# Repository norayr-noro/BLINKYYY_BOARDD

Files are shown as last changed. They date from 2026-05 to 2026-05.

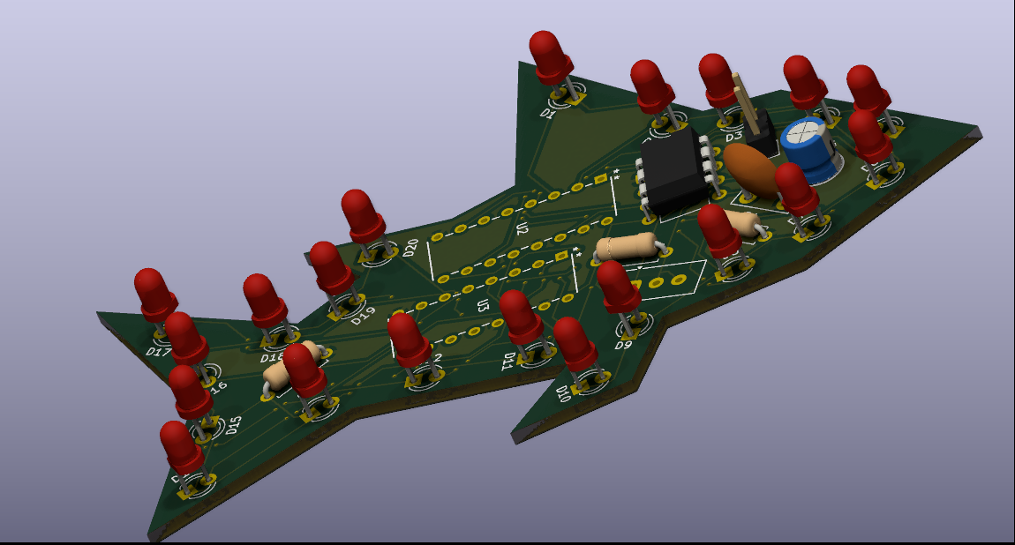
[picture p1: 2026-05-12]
BLINKYY_photos/PCB(3d).png

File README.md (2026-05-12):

# BLINKYYY_BOARDD
This project is based on the stasis guide on the blinky board, where I mostly followed the guide and changed the final look of the PCB to be a FISH (a FIH if you may):

The circuit is based on the original LED chaser design using a 555 timer IC and a CD4017 decade counter. The LEDs light up sequentially, creating a moving animation around the fish-shaped board. While the electronics stay close to the original tutorial, most of the work went into redesigning the PCB layout and making the board look unique.

# Process

The project, first of all, went through the schematic stage as all projects do. It wasn't anything too interesting. For this project ill be using KiCad.  The guide used a 555 chaser and a 4017 IC, which sounds like random letters and words, but kinda makes sense if you think about it. For example, the 555 timer in this build is kinda the "brain" of the whole build, and as far as I understand, the name comes from the 3x 5K ohm internal resistance, while for the IC unit it would help me connect 10 LED's to the board with ease because it has so many pins (think of it as a "spreader" here). Other than those 2 parts, the other parts in the kit are really simple, like an LED, resistors, a polarized (+ and - differentiate in this one, so be careful when wiring!), and a normal capacitor (don't forget the potentiometer too!!).

After understanding what everything dose the next step was to wire all of them, which wasn't difficult at all, except for the wiring for the 555 timer. For context, the timer has 3 modes:
- Monostable (for time delays) mode, which is usually used as a stopwatch
- Astable Mode, which shifts between high and low
- Bistable Mode, which is like a toggle mode (eg a LED turning on and off with different buttons)
For my build, I followed the Astable mode, which has a bit of a weird wiring, but it wasn't too hard.
Also, usually when routing, I learnt it's better to label wires (by pressing A) so it's easier to understand than to wire everything in one fell swoop.
After all of that, the schematic looks a bit like this:

schematic_photo

# The PCB 

Finally, were are onto the PCB designing. Before this, of course you first had to add footprints, obviously. Don't know what they are thinking of symbols and footprints like this, imagine a symbol, something used to understand how a part has to be routed, it's for our case, the symbols are the 555 timer, the IC... everything on the schematic that counts as a part is, and as for footprints Its how the part would look like on the real pcb itself. So I mostly did the same footprints assigning like on the guide this:(+ you will have to download the footprint from [sign in and download](https://app.ultralibrarian.com/details/15b11d40-103f-11e9-ab3a-0a3560a4cccc/Texas-Instruments/CD4017BE]) )

b4llal

After that, open the PCB designing on KiCad and press F8 or just click update PCB from schematic,  and boom, you're almost done. The next logical step would be to make your own design and place parts and finally route everything, and you're finished (sounds like a lot, but  it's actually not that difficult)
In the PCB, I changed the whole look of it by changing the Edge.Cuts (which are like where the PCB must be cut to get that shape) using the tools on the bottom and middle right. For me, it was in the shape of a Fish...
One of the most interesting parts of this project was adapting the circuit into a non-standard shape. Since the board outline was no longer rectangular, component placement and routing became much more challenging. I had to carefully position LEDs and traces so the board still looked clean while maintaining proper electrical connections.
Finishing off, you usually place the parts on the PCB and route it by placing traces of copper to connect the parts highlighted.

## Tools Used
- KiCad
- GitHub
- JLCPCB
- Hack Club Stasis Guide

## Preview
Here's the final look of the project:
(At the end, I added an extra IC to connect more LED's to make the spiral blinking look cooler and smoother)
schematic_photo(final)
PCB(2d)
PCB(3d)

## Credits
Original guide and inspiration:
- Hack Club Stasis
- Hack Club Blueprint

Guide used:
https://stasis.hackclub.com/starter-projects/blinky

## Conclusion
Overall this is a perfect project for a begginer to start getting into making these cool custom PCB's and, I really recommend people who start getting into this type of hobby to start from a reallyy easy project like this!Big thanks to [Hack Club Stasis](https://stasis.hackclub.com/starter-projects/blinky?utm_source=chatgpt.com) for the awesome beginner-friendly PCB guide that helped me learn PCB design and customization.

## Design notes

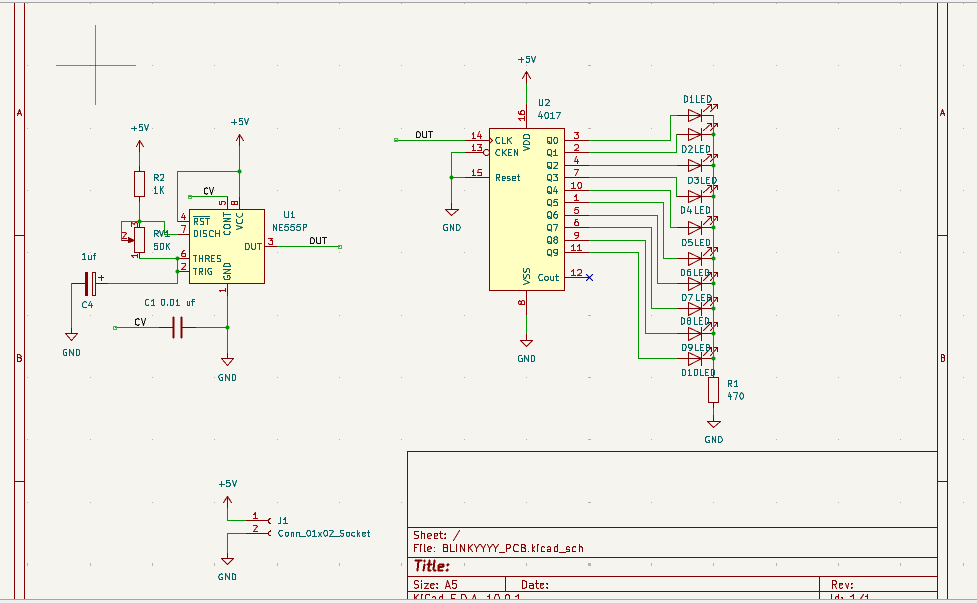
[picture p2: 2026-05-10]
BLINKYY_photos/schematic_photo.png

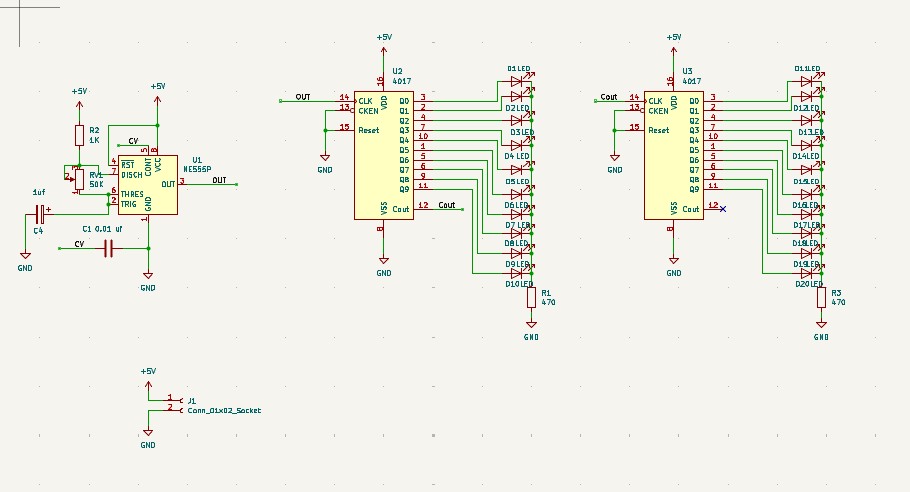
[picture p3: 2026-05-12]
BLINKYY_photos/schematic_photo(final).png

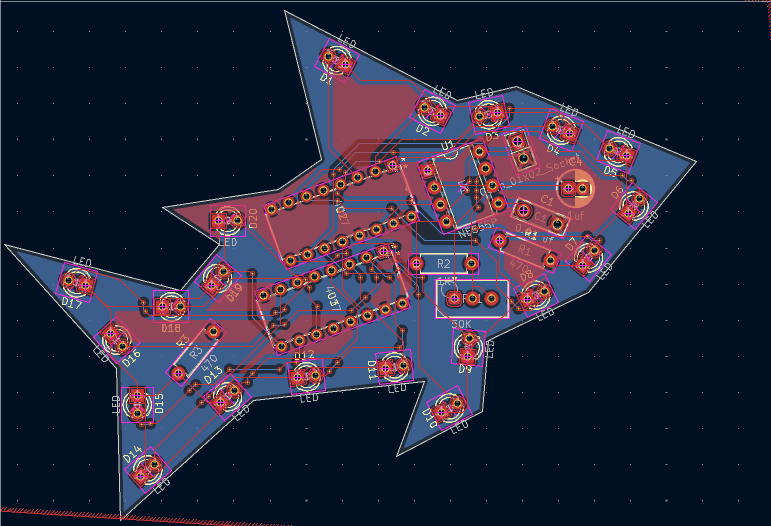
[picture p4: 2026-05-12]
BLINKYY_photos/PCB(2d).png

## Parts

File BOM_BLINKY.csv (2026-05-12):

 | Price valued per unit and total price PER BOARD
Item | URL | Price | Quantity needed | Total
The PCB | https://jlcpcb.com/ | 4 | 1 | 4
LED's | https://shorturl.at/o8qgg | 0.33 | 20 | 6.56
555 timer | https://shorturl.at/ZReW3 | 0.8 | 1 | 3.99
IC 4017 | https://shorturl.at/sjAKj | 1.27 | 2 | 2.54
Subtotal (only parts) | 17.09
Shipping and handling | 10.5
Total (with fees) | 27.14
Total needed from stasis | 0

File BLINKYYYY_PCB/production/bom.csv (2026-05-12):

Designator | Footprint | Quantity | Value | LCSC Part #
C1 | C_Disc_D7.5mm_W2.5mm_P5.00mm | 1 | 0.01 uf
C4 | CP_Radial_D5.0mm_P2.00mm | 1 | 1uf
D1, D10, D11, D12, D13, D14, D15, D16, D17, D18, D19, D2, D20, D3, D4, D5, D6, D7, D8, D9 | LED_D3.0mm | 20 | LED
J1 | PinHeader_1x02_P2.54mm_Vertical | 1 | Conn_01x02_Socket
R1, R3 | R_Axial_DIN0207_L6.3mm_D2.5mm_P7.62mm_Horizontal | 2 | 470
R2 | R_Axial_DIN0207_L6.3mm_D2.5mm_P7.62mm_Horizontal | 1 | 1K
RV1 | Potentiometer_Vishay_T93YA_Vertical | 1 | 50K
U1 | DIP-8_W7.62mm | 1 | NE555P
U2, U3 | N16 | 2 | 4017

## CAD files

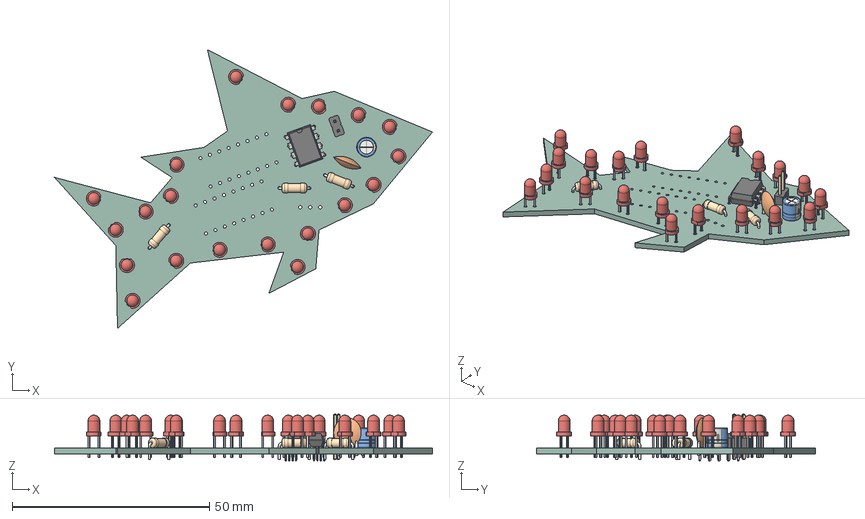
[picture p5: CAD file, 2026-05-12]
BLINKYYYY_PCB/Blinky.step
95.9 x 70.7 x 11.8 mm
LED_D3.0mm x 20
DIP-8_W7.62mm
R_Axial_DIN0207_L6.3mm_D2.5mm_P7.62mm_Horizontal x 3
PinHeader_1x02_P2.54mm_Vertical
CP_Radial_D5.0mm_P2.00mm
C_Disc_D7.5mm_W2.5mm_P5.00mm
BLINKYYYY_PCB_PCB

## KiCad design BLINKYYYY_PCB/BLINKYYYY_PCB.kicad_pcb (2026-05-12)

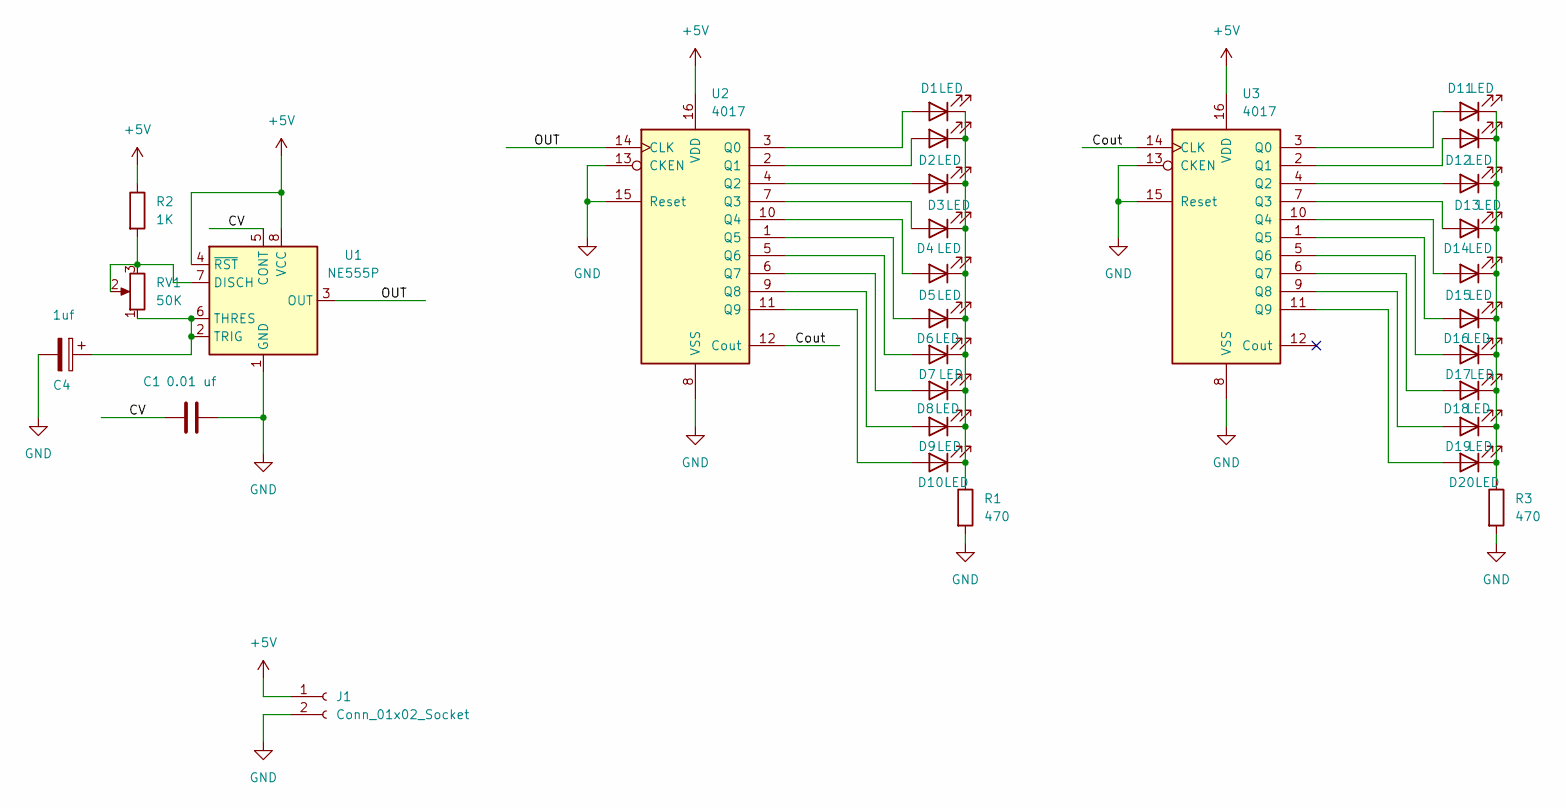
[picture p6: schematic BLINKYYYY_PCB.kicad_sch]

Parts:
C1: 0.01 uf; C_Disc_D7.5mm_W2.5mm_P5.00mm
C4: 1uf; CP_Radial_D5.0mm_P2.00mm
D1, D2, D3, D4, D5, D6, D7, D8, D9, D10, D11, D12, D13, D14, D15, D16, D17, D18, D19, D20: LED; LED_D3.0mm
J1: Conn_01x02_Socket; PinHeader_1x02_P2.54mm_Vertical
R1, R3: 470; R_Axial_DIN0207_L6.3mm_D2.5mm_P7.62mm_Horizontal
R2: 1K; R_Axial_DIN0207_L6.3mm_D2.5mm_P7.62mm_Horizontal
RV1: 50K; Potentiometer_Vishay_T93YA_Vertical
U1: NE555P; DIP-8_W7.62mm
U2, U3: 4017; N16

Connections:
+5V: J1.1, R2.1, U1.4 (~RST), U1.8 (VCC), U2.16 (VDD), U3.16 (VDD)
/CV: C1.1, U1.5 (CONT)
/Cout: U2.12 (Cout), U3.14 (CLK)
/OUT: U1.3 (OUT), U2.14 (CLK)
GND: C1.2, C4.2, J1.2, R1.2, R3.2, U1.1 (GND), U2.8 (VSS), U2.13 (CKEN), U2.15 (Reset), U3.8 (VSS), U3.13 (CKEN), U3.15 (Reset)
unnamed: D1.2 (A), U2.3 (Q0)
unnamed: D1.1 (K), D2.1 (K), D3.1 (K), D4.1 (K), D5.1 (K), D6.1 (K), D7.1 (K), D8.1 (K), D9.1 (K), D10.1 (K), R1.1
unnamed: D2.2 (A), U2.2 (Q1)
unnamed: D3.2 (A), U2.4 (Q2)
unnamed: D4.2 (A), U2.7 (Q3)
unnamed: D5.2 (A), U2.10 (Q4)
unnamed: D6.2 (A), U2.1 (Q5)
unnamed: D7.2 (A), U2.5 (Q6)
unnamed: D8.2 (A), U2.6 (Q7)
unnamed: D9.2 (A), U2.9 (Q8)
unnamed: D10.2 (A), U2.11 (Q9)
unnamed: D11.2 (A), U3.3 (Q0)
unnamed: D11.1 (K), D12.1 (K), D13.1 (K), D14.1 (K), D15.1 (K), D16.1 (K), D17.1 (K), D18.1 (K), D19.1 (K), D20.1 (K), R3.1
unnamed: D12.2 (A), U3.2 (Q1)
unnamed: D13.2 (A), U3.4 (Q2)
unnamed: D14.2 (A), U3.7 (Q3)
unnamed: D15.2 (A), U3.10 (Q4)
unnamed: D16.2 (A), U3.1 (Q5)
unnamed: D17.2 (A), U3.5 (Q6)
unnamed: D18.2 (A), U3.6 (Q7)
unnamed: D19.2 (A), U3.9 (Q8)
unnamed: D20.2 (A), U3.11 (Q9)
unnamed: R2.2, RV1.2, RV1.3, U1.7 (DISCH)
unnamed: C4.1, RV1.1, U1.2 (TRIG), U1.6 (THRES)

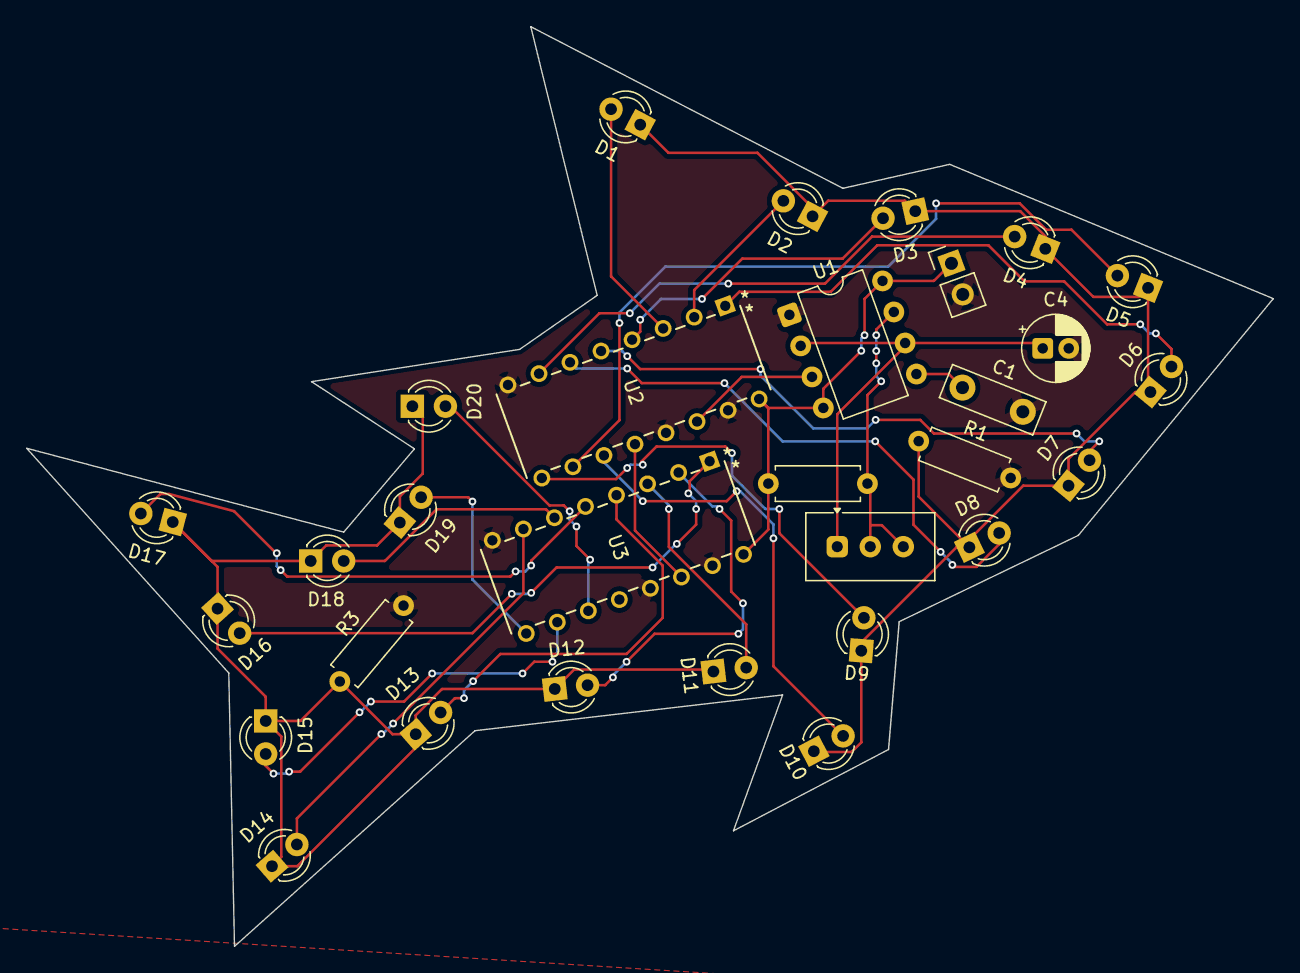
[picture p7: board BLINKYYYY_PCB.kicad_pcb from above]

Board: 2 copper layers, 95.9 x 70.7 mm, 30 parts (0 on the bottom side), 29 nets.

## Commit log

2026-05-10 Enhance README with project details and process
    Expanded project description, added process details, and included tools used for PCB design. Updated credits and conclusion sections for clarity.
2026-05-12 Delete BLINKYYYY_PCB directory
    deleted directory due to change in pcb
    [BLINKYYYY_PCB.kicad_pcb, BLINKYYYY_PCB.kicad_sch, LoRa_board(a).step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]
2026-05-12 Update README to enhance project preview section
    Removed duplicate PCB images and added a note about an extra IC for improved LED effects.
